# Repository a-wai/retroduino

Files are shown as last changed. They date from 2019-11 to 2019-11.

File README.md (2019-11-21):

# RetroDuino

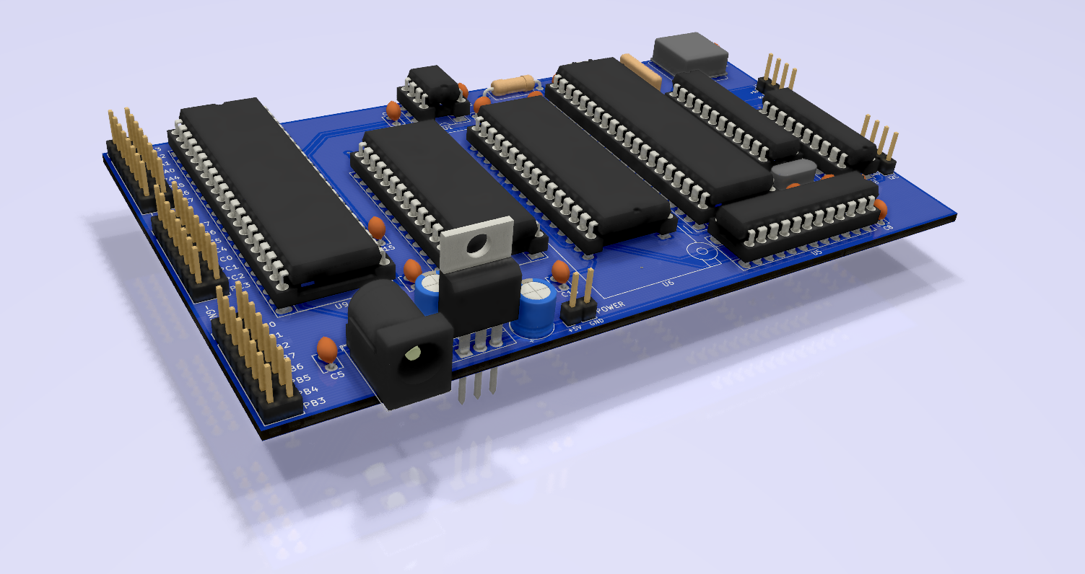
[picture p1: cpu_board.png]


The RetroDuino is an attempt at designing and building an 8-bit microcomputer,
using a 6502 processor, and offering a number of I/O options, as commonly found
on Arduino boards.

## Features

This 130x75mm SBC (Single Board Computer) provides a UART interface, an I2C bus#
and 24 GPIOs.

It includes 31kB of SRAM, 32kB of flash memory (mounted on a ZIF socket for
easier programming), and runs at 8MHz.

## Internals

The RetroDuino includes:

- 1 65C02 processsor w/ 8MHz oscillator
- 1 GAL22V10 for address decoding logic
- 1 AS6C62256 32kB SRAM
- 1 SST39SF010/020/040 flash memory, of which only 32kB is used
- 1 SCC2691 UART controller
- 1 PCF8584 I2C controller
- 1 82C55A peripheral interface providing 24 GPIO lines

It can be powered using a 7-24V DC power supply.

## Current status

This project is still in its infancy: hardware design is complete, but not
tested yet. The next steps are:

- [ ] program and test the GAL logic
- [ ] prototype a flash programmer (probably using a STM32 board)
- [ ] order the board and build the project
- [ ] write the software

## Why?

Why go through so much pain, when hundreds of microcontroller boards are
widely available and so cheap? Because... Well, it's fun!

And as a positive side effect, this is a good way to learn a lot about the
internals of modern microcontrollers, or computers in general.

## Licensing

Copyright 2019, Arnaud Ferraris.

This documentation describes Open Hardware and is licensed under the
CERN OHL v.1.2.

You may redistribute and modify this documentation under the terms of the
[CERN OHL v.1.2](http://ohwr.org/cernohl). This documentation is distributed
WITHOUT ANY EXPRESS OR IMPLIED WARRANTY, INCLUDING OF MERCHANTABILITY,
SATISFACTORY QUALITY AND FITNESS FOR A PARTICULAR PURPOSE.

Please see the CERN OHL v.1.2 for applicable conditions.

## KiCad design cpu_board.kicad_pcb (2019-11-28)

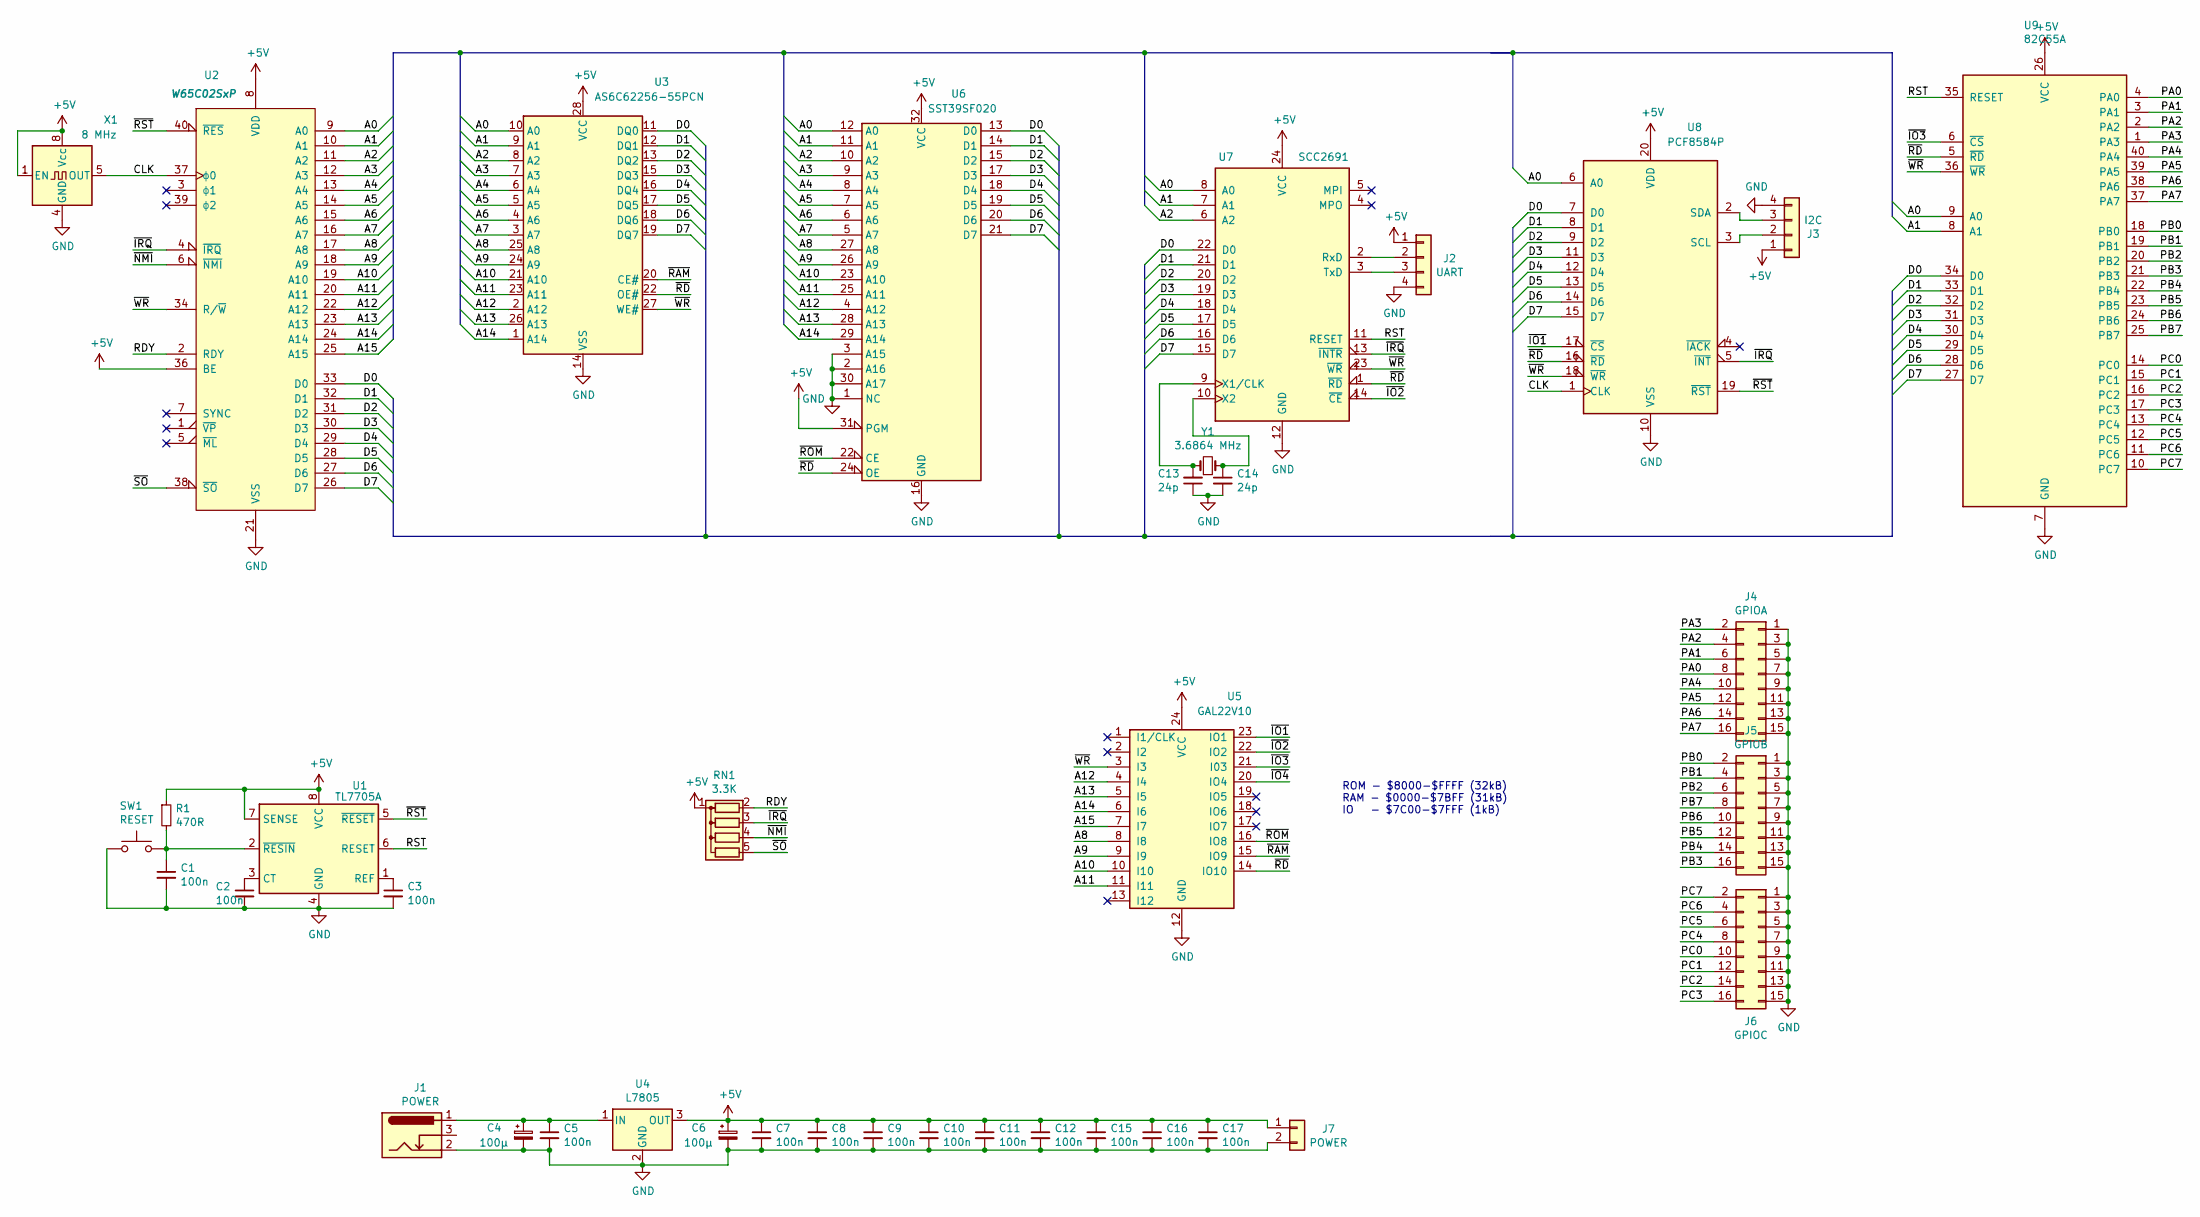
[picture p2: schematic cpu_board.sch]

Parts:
C1, C2, C3, C5, C7, C8, C9, C10, C11, C12, C15, C16, C17: 100n; C_Disc_D3.8mm_W2.6mm_P2.50mm
C4, C6: 100µ; CP_Radial_D6.3mm_P2.50mm
C13, C14: 24p; C_Disc_D3.8mm_W2.6mm_P2.50mm
J1: POWER; BarrelJack_Horizontal
J2: UART; PinHeader_1x04_P2.54mm_Vertical
J3: I2C; PinHeader_1x04_P2.54mm_Vertical
J4: GPIOA; PinHeader_2x08_P2.54mm_Vertical
J5: GPIOB; PinHeader_2x08_P2.54mm_Vertical
J6: GPIOC; PinHeader_2x08_P2.54mm_Vertical
J7: POWER; PinHeader_1x02_P2.54mm_Vertical
R1: 470R; R_Axial_DIN0309_L9.0mm_D3.2mm_P12.70mm_Horizontal
RN1: 3.3K; R_Array_SIP5
SW1: RESET; SW_PUSH_6mm
U1: TL7705A; DIP-8_W7.62mm_Socket_LongPads
U2: W65C02SxP; DIP-40_W15.24mm_Socket_LongPads
U3: AS6C62256-55PCN; DIP-28_W15.24mm_Socket_LongPads
U4: L7805; TO-220-3_Vertical
U5: GAL22V10; DIP-24_W7.62mm_Socket_LongPads
U6: SST39SF020; DIP_Socket-32_W11.9_W12.7_W15.24_W17.78_W18.5_3M_232-1285-0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
U7: SCC2691; DIP-24_W7.62mm_Socket_LongPads
U8: PCF8584P; DIP-20_W7.62mm_Socket_LongPads
U9: 82C55A; DIP-40_W15.24mm_Socket_LongPads
X1: 8 MHz; Oscillator_DIP-8_LargePads
Y1: 3.6864 MHz; Crystal_HC49-U_Vertical

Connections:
+5V: C6.1, C7.1, C8.1, C9.1, C10.1, C11.1, C12.1, C15.1, C16.1, C17.1, J2.1, J3.1, J7.1, R1.1, RN1.1 (common), U1.7 (SENSE), U1.8 (VCC), U2.8 (VDD), U2.36 (BE), U3.28 (VCC), U4.3 (OUT), U5.24 (VCC), U6.31 (PGM), U6.32 (VCC), U7.24 (VCC), U8.20 (VDD), U9.26 (VCC), X1.1 (EN), X1.8 (Vcc)
/A0: U2.9 (A0), U3.10 (A0), U6.12 (A0), U7.8 (A0), U8.6 (A0), U9.9 (A0)
/A1: U2.10 (A1), U3.9 (A1), U6.11 (A1), U7.7 (A1), U9.8 (A1)
/A2: U2.11 (A2), U3.8 (A2), U6.10 (A2), U7.6 (A2)
/A3: U2.12 (A3), U3.7 (A3), U6.9 (A3)
/A4: U2.13 (A4), U3.6 (A4), U6.8 (A4)
/A5: U2.14 (A5), U3.5 (A5), U6.7 (A5)
/A6: U2.15 (A6), U3.4 (A6), U6.6 (A6)
/A7: U2.16 (A7), U3.3 (A7), U6.5 (A7)
/A8: U2.17 (A8), U3.25 (A8), U5.8 (I8), U6.27 (A8)
/A9: U2.18 (A9), U3.24 (A9), U5.9 (I9), U6.26 (A9)
/A10: U2.19 (A10), U3.21 (A10), U5.10 (I10), U6.23 (A10)
/A11: U2.20 (A11), U3.23 (A11), U5.11 (I11), U6.25 (A11)
/A12: U2.22 (A12), U3.2 (A12), U5.4 (I4), U6.4 (A12)
/A13: U2.23 (A13), U3.26 (A13), U5.5 (I5), U6.28 (A13)
/A14: U2.24 (A14), U3.1 (A14), U5.6 (I6), U6.29 (A14)
/A15: U2.25 (A15), U5.7 (I7)
/CLK: U2.37 (ϕ0), U8.1 (CLK), X1.5 (OUT)
/D0: U2.33 (D0), U3.11 (DQ0), U6.13 (D0), U7.22 (D0), U8.7 (D0), U9.34 (D0)
/D1: U2.32 (D1), U3.12 (DQ1), U6.14 (D1), U7.21 (D1), U8.8 (D1), U9.33 (D1)
/D2: U2.31 (D2), U3.13 (DQ2), U6.15 (D2), U7.20 (D2), U8.9 (D2), U9.32 (D2)
/D3: U2.30 (D3), U3.15 (DQ3), U6.17 (D3), U7.19 (D3), U8.11 (D3), U9.31 (D3)
/D4: U2.29 (D4), U3.16 (DQ4), U6.18 (D4), U7.18 (D4), U8.12 (D4), U9.30 (D4)
/D5: U2.28 (D5), U3.17 (DQ5), U6.19 (D5), U7.17 (D5), U8.13 (D5), U9.29 (D5)
/D6: U2.27 (D6), U3.18 (DQ6), U6.20 (D6), U7.16 (D6), U8.14 (D6), U9.28 (D6)
/D7: U2.26 (D7), U3.19 (DQ7), U6.21 (D7), U7.15 (D7), U8.15 (D7), U9.27 (D7)
/PA0: J4.8, U9.4 (PA0)
/PA1: J4.6, U9.3 (PA1)
/PA2: J4.4, U9.2 (PA2)
/PA3: J4.2, U9.1 (PA3)
/PA4: J4.10, U9.40 (PA4)
/PA5: J4.12, U9.39 (PA5)
/PA6: J4.14, U9.38 (PA6)
/PA7: J4.16, U9.37 (PA7)
/PB0: J5.2, U9.18 (PB0)
/PB1: J5.4, U9.19 (PB1)
/PB2: J5.6, U9.20 (PB2)
/PB3: J5.16, U9.21 (PB3)
/PB4: J5.14, U9.22 (PB4)
/PB5: J5.12, U9.23 (PB5)
/PB6: J5.10, U9.24 (PB6)
/PB7: J5.8, U9.25 (PB7)
/PC0: J6.10, U9.14 (PC0)
/PC1: J6.12, U9.15 (PC1)
/PC2: J6.14, U9.16 (PC2)
/PC3: J6.16, U9.17 (PC3)
/PC4: J6.8, U9.13 (PC4)
/PC5: J6.6, U9.12 (PC5)
/PC6: J6.4, U9.11 (PC6)
/PC7: J6.2, U9.10 (PC7)
/RDY: RN1.2 (R1), U2.2 (RDY)
/RST: U1.6 (RESET), U7.11 (RESET), U9.35 (RESET)
/~IO1~: U5.23 (IO1), U8.17 (~CS~)
/~IO2~: U5.22 (IO2), U7.14 (~CE~)
/~IO3~: U5.21 (I03), U9.6 (~CS~)
/~IRQ~: RN1.3 (R2), U2.4 (~IRQ), U7.13 (~INTR~), U8.5 (~INT~)
/~NMI~: RN1.4 (R3), U2.6 (~NMI)
/~RAM~: U3.20 (CE#), U5.15 (IO9)
/~RD~: U3.22 (OE#), U5.14 (IO10), U6.24 (OE), U7.1 (~RD~), U8.16 (~RD~), U9.5 (~RD~)
/~ROM~: U5.16 (IO8), U6.22 (CE)
/~RST~: U1.5 (~RESET), U2.40 (~RES), U8.19 (~RST~)
/~SO~: RN1.5 (R4), U2.38 (~SO)
/~WR~: U2.34 (R/~W), U3.27 (WE#), U5.3 (I3), U7.23 (~WR~), U8.18 (~WR~), U9.36 (~WR~)
GND: C1.2, C2.2, C3.2, C4.2, C5.2, C6.2, C7.2, C8.2, C9.2, C10.2, C11.2, C12.2, C13.1, C14.2, C15.2, C16.2, C17.2, J1.2, J2.4, J3.4, J4.1, J4.3, J4.5, J4.7, J4.9, J4.11, J4.13, J4.15, J5.1, J5.3, J5.5, J5.7, J5.9, J5.11, J5.13, J5.15, J6.1, J6.3, J6.5, J6.7, J6.9, J6.11, J6.13, J6.15, J7.2, SW1.1, U1.4 (GND), U2.21 (VSS), U3.14 (VSS), U4.2 (GND), U5.12 (GND), U6.1 (NC), U6.2 (A16), U6.3 (A15), U6.16 (GND), U6.30 (A17), U7.12 (GND), U8.10 (VSS), U9.7 (GND), X1.4 (GND)
unnamed: C1.1, R1.2, SW1.2, U1.2 (~RESIN)
unnamed: C2.1, U1.3 (CT)
unnamed: C3.1, U1.1 (REF)
unnamed: C4.1, C5.1, J1.1, U4.1 (IN)
unnamed: C13.2, U7.9 (X1/CLK), Y1.1
unnamed: C14.1, U7.10 (X2), Y1.2
unnamed: J2.2, U7.2 (RxD)
unnamed: J2.3, U7.3 (TxD)
unnamed: J3.2, U8.3 (SCL)
unnamed: J3.3, U8.2 (SDA)

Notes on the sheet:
ROM - $8000-$FFFF (32kB) RAM - $0000-$7BFF (31kB) IO - $7C00-$7FFF (1kB)

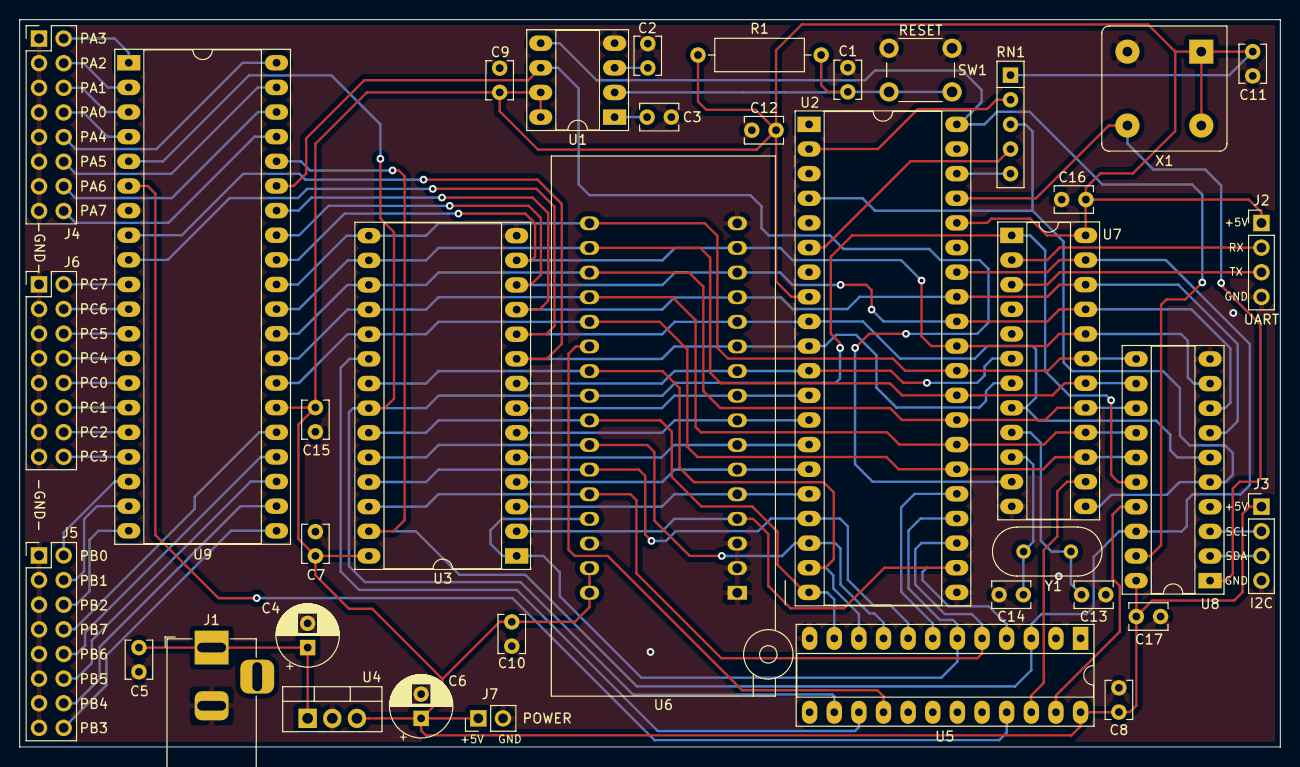
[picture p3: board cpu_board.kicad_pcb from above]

Board: 2 copper layers, 130.0 x 75.0 mm, 38 parts (0 on the bottom side), 74 nets.

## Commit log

2019-11-21 Initial import
    [cpu_board.kicad_pcb, cpu_board.sch]
2019-11-27 Fix capacitors footprints & add POWER header
    [cpu_board.kicad_pcb, cpu_board.sch]
2019-11-28 Add pull-ups for unused CPU inputs
    [cpu_board.kicad_pcb, cpu_board.sch]
2019-11-28 Add gerber files
    [cpu_board-B_Cu.gbl, cpu_board-B_Mask.gbs, cpu_board-Edge_Cuts.gm1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]
